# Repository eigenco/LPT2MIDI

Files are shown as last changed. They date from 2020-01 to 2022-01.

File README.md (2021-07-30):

# LPT2MIDI
- LPT2MIDI is a parallel printer port (LPT) to MIDI adapter.
- Autodesk Eagle PCB files are included.
- Uses Arduino IRQ to trigger pin reads and forwards the data to MIDI serial buffer (MIDI uses 31250 bps).
- A simple port trapping code for MS-DOS is included. This for the time being works for direct midi commands to port 330h only.
- Quickly modified version of SOFTMPU for MPU-401 compatibility.
- Tested with Roland MT-32 and Supaplex (an old MS-DOS game, requires minor modification to the code).
- Requires power through USB while operating.

Youtube link of the device in action: https://www.youtube.com/watch?v=MyJpt-w3Oao

LPT2MIDI

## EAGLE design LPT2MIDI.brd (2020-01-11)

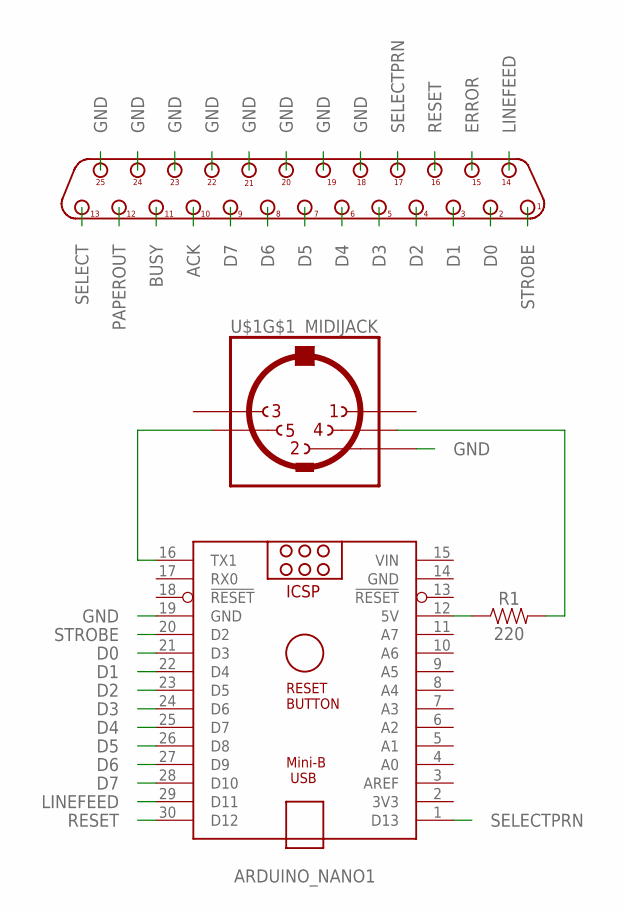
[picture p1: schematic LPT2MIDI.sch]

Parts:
ARDUINO_NANO1: ARDUINO_NANO
CON1: DB25M/90; D-25M/90
R1: 220; AXIAL-0.3
U$1: MIDIJACK; CP-2350

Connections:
ACK: CON1.10
BUSY: CON1.11
D0: ARDUINO_NANO1.21 (D3), CON1.2
D1: ARDUINO_NANO1.22 (D4), CON1.3
D2: ARDUINO_NANO1.23 (D5), CON1.4
D3: ARDUINO_NANO1.24 (D6), CON1.5
D4: ARDUINO_NANO1.25 (D7), CON1.6
D5: ARDUINO_NANO1.26 (D8), CON1.7
D6: ARDUINO_NANO1.27 (D9), CON1.8
D7: ARDUINO_NANO1.28 (D10), CON1.9
ERROR: CON1.15
GND: ARDUINO_NANO1.14 (GND), ARDUINO_NANO1.19 (GND), CON1.18, CON1.19, CON1.20, CON1.21, CON1.22, CON1.23, CON1.24, CON1.25, U$1.2
LINEFEED: ARDUINO_NANO1.29 (D11), CON1.14
unnamed: ARDUINO_NANO1.12 (5V), R1.P$1 (1)
unnamed: R1.P$2 (2), U$1.4
unnamed: ARDUINO_NANO1.16 (TX1), U$1.5
PAPEROUT: CON1.12
RESET: ARDUINO_NANO1.30 (D12), CON1.16
SELECT: CON1.13
SELECTPRN: ARDUINO_NANO1.1 (D13), CON1.17
STROBE: ARDUINO_NANO1.20 (D2), CON1.1
VIN: ARDUINO_NANO1.15 (VIN)

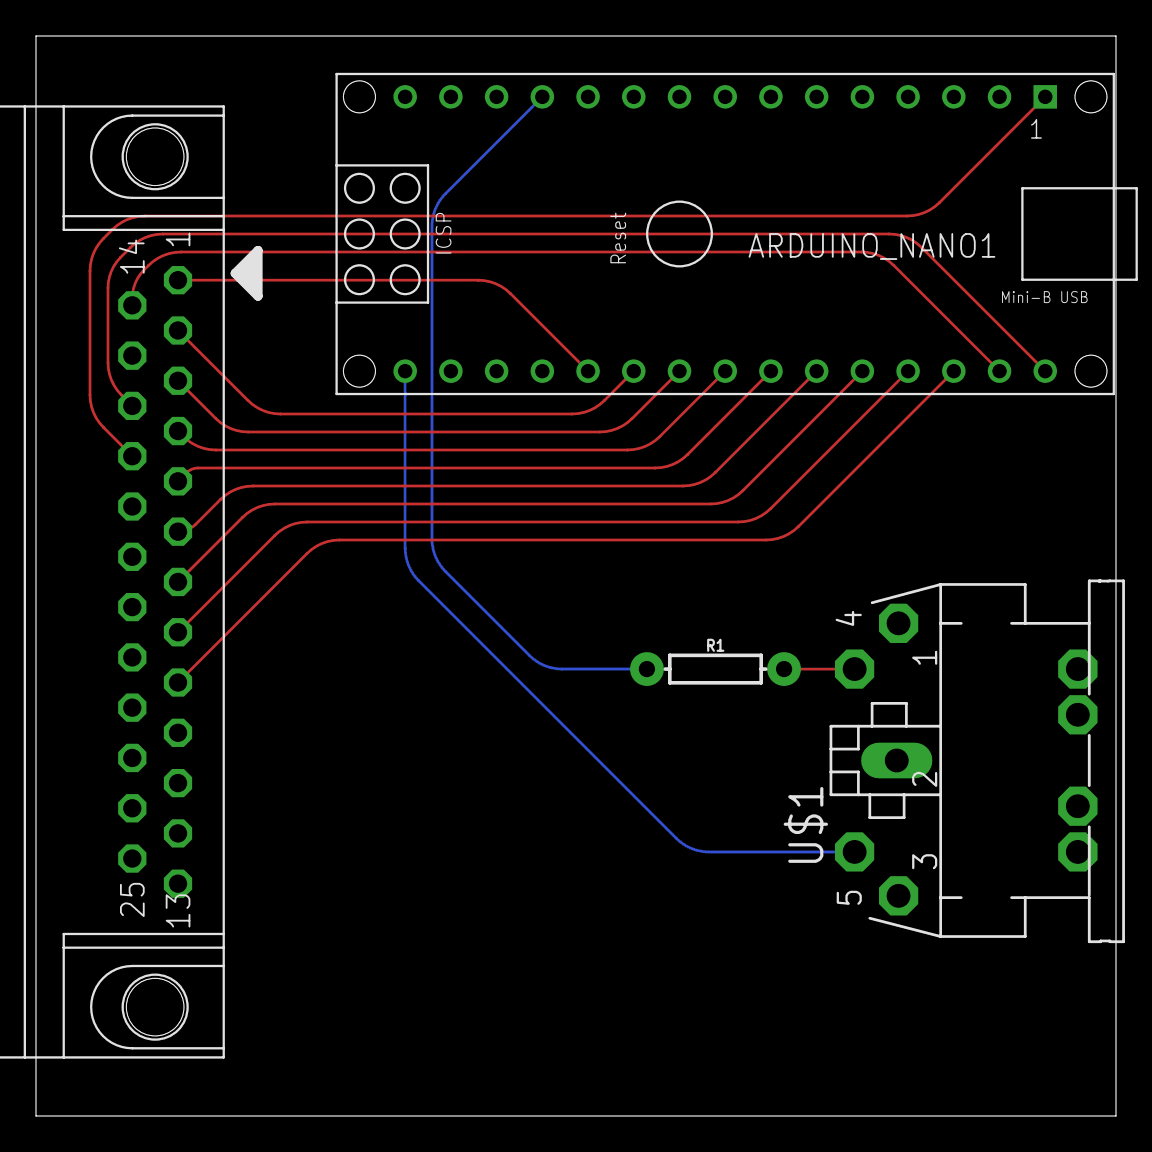
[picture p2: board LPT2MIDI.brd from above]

Board: 2 copper layers, 60.0 x 60.0 mm, 4 parts (0 on the bottom side), 16 nets.

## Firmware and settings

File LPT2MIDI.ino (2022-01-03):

#include "Fifo.h"

static Fifo<byte, 192> fifo;

void setup() {
  static byte MASKB = B00000111; // Using lower 3 bits of the B port
  static byte MASKD = B11111000; // Using upper 5 bits of the D port
  // Set only the required bits to input, leaving all the other bits unchanged
  DDRB &= ~MASKB;
  DDRD &= ~MASKD;
  Serial.begin(31250);
  auto receive = []() { fifo.push(((PIND & MASKD) >> 3) | ((PINB & MASKB) << 5)); };
  attachInterrupt(digitalPinToInterrupt(2), receive, RISING);
}

void loop() {
  // TODO: we could check here for fifo overflow using the fifo.full()
  //       function and notifying somehow the user. May be by blinking
  //       the LED?
  if (!fifo.empty()) {
    Serial.write(fifo.pop());
  }
}

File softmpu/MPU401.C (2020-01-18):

/*
 *  Copyright (C) 2002-2012  The DOSBox Team
 *  Copyright (C) 2013-2014  bjt, elianda
 *
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
 *  You should have received a copy of the GNU General Public License
 *  along with this program; if not, write to the Free Software
 *  Foundation, Inc., 59 Temple Place - Suite 330, Boston, MA 02111-1307, USA.
 */

/*
 * ------------------------------------------
 * SoftMPU by bjt - Software MPU-401 Emulator
 * ------------------------------------------
 *
 * Based on original mpu401.c from DOSBox
 *
 */

/* SOFTMPU: Moved exported functions & types to header */
#include "export.h"

/* SOFTMPU: Don't need these includes */
/*#include <string.h>
#include "dosbox.h"
#include "inout.h"
#include "pic.h"
#include "setup.h"
#include "cpu.h"
#include "support.h"*/

/* SOFTMPU: Additional defines, typedefs etc. for C */
typedef unsigned short Bit16u;
typedef int Bits;

/*typedef void (*PIC_EventHandler)(Bitu val);*/ /* SOFTMPU */

/* SOFTMPU: Stubbed functions */
void PIC_Init(void); /* SOFTMPU */
void PIC_ActivateIRQ(Bitu sbport); /* SOFTMPU */
void PIC_DeActivateIRQ(Bitu sbport); /* SOFTMPU */
void PIC_SetIRQMask(Bitu irq,bool masked);
void PIC_AddEvent(EventID event,Bitu delay);
void PIC_RemoveEvents(EventID event);

void MIDI_Init(Bitu mpuport,Bitu sbport,Bitu serialport,OutputMode outputmode,bool delaysysex,bool fakeallnotesoff);
void MIDI_RawOutByte(Bit8u data);
bool MIDI_Available(void);

void MPU401_Event(void);
void MPU401_ResetDone(void); /* SOFTMPU */
void MPU401_EOIHandler(void);
static void MPU401_Reset(void);
static void MPU401_EOIHandlerDispatch(void);

#define MPU401_VERSION  0x15
#define MPU401_REVISION 0x01
#define MPU401_QUEUE 32
#define MPU401_TIMECONSTANT 58000 /* SOFTMPU: Was 60000 */
#define MPU401_RESETBUSY 27*(RTCFREQ/1000) /* SOFTMPU */

enum MpuMode { M_UART,M_INTELLIGENT };
typedef enum MpuMode MpuMode; /* SOFTMPU */
enum MpuDataType {T_OVERFLOW,T_MARK,T_MIDI_SYS,T_MIDI_NORM,T_COMMAND};
typedef enum MpuDataType MpuDataType; /* SOFTMPU */

/* Messages sent to MPU-401 from host */
#define MSG_EOX                         0xf7
#define MSG_OVERFLOW                    0xf8
#define MSG_MARK                        0xfc

/* Messages sent to host from MPU-401 */
#define MSG_MPU_OVERFLOW                0xf8
#define MSG_MPU_COMMAND_REQ             0xf9
#define MSG_MPU_END                     0xfc
#define MSG_MPU_CLOCK                   0xfd
#define MSG_MPU_ACK                     0xfe

static struct {
	bool intelligent;
	bool generate_irqs; /* SOFTMPU */
	bool mpu_ver_fix; /* SOFTMPU */
	MpuMode mode;
	Bitu sbport;
	Bitu mpuport;
	Bitu serialport;
	/*Bitu irq;*/ /* SOFTMPU */
	Bit8u queue[MPU401_QUEUE];
	Bitu queue_pos,queue_used;
	struct track {
		Bits counter;
		Bit8u value[8],sys_val;
		Bit8u vlength,length;
		MpuDataType type;
	} playbuf[8],condbuf;
	struct {
		bool conductor,cond_req,cond_set, block_ack;
		bool playing,reset;
		bool wsd,wsm,wsd_start;
		bool run_irq,irq_pending;
		bool send_now;
		bool eoi_scheduled;
		Bits data_onoff;
		Bitu command_byte,cmd_pending;
		Bit8u tmask,cmask,amask;
		Bit16u midi_mask;
		Bit16u req_mask;
		Bit8u channel,old_chan;
	} state;
	struct {
		Bit8u timebase,old_timebase;
		Bit8u tempo,old_tempo;
		Bit8u tempo_rel,old_tempo_rel;
		Bit8u tempo_grad;
		Bit8u cth_rate,cth_counter;
		bool clock_to_host,cth_active;
	} clock;
} mpu;

/* SOFTMPU: Global QEMM interface parameters accessed from MIDI_PlayMsg */
QEMMInfo qemm = { false, NULL }; /* Disabled by default */

/* SOFTMPU: Selected output mode */
extern MIDI_output_mode;

static void QueueByte(Bit8u data) {
	if (mpu.state.block_ack) {mpu.state.block_ack=false;return;}
	if (mpu.queue_used==0 && mpu.intelligent && mpu.generate_irqs) {
		mpu.state.irq_pending=true;
		PIC_ActivateIRQ(mpu.sbport); /* SOFTMPU */
	}
	if (mpu.queue_used<MPU401_QUEUE) {
		Bitu pos=mpu.queue_used+mpu.queue_pos;
		if (mpu.queue_pos>=MPU401_QUEUE) mpu.queue_pos-=MPU401_QUEUE;
		if (pos>=MPU401_QUEUE) pos-=MPU401_QUEUE;
		mpu.queue_used++;
		mpu.queue[pos]=data;
	} /*else LOG(LOG_MISC,LOG_NORMAL)("MPU401:Data queue full");*/ /* SOFTMPU */
}

static void ClrQueue(void) {
	mpu.queue_used=0;
	mpu.queue_pos=0;
}

Bitu MPU401_ReadStatus(void) { /* SOFTMPU */
	Bit8u retval=0x3f; /* Bits 6 and 7 clear */

	switch (MIDI_output_mode)
	{
	case M_MPU401:
		/* SOFTMPU: Reflect hardware DRR */
		_asm
		{
				mov     dx,mpu.mpuport
				inc     dx
				cmp     qemm.installed,1
				jne     UntrappedIn3
				mov     ax,01A00h               ; QPI_UntrappedIORead
				call    qemm.qpi_entry          ; Result in bl
				mov     al,bl
				_emit   0A8h                    ; Emit test al,(next opcode byte)
								; Effectively skips next instruction
		UntrappedIn3:   in      al,dx
				and     al,040h
				or      retval,al
		}
		break;
	case M_SBMIDI:
		/* SOFTMPU: Reflect hardware WBS */
		_asm
		{
				mov     dx,mpu.sbport
				add     dx,0Ch                  ; Select DSP write port
				cmp     qemm.installed,1
				jne     UntrappedIn
				mov     ax,01A00h               ; QPI_UntrappedIORead
				call    qemm.qpi_entry          ; Result in bl
				mov     al,bl
				_emit   0A8h                    ; Emit test al,(next opcode byte)
								; Effectively skips next instruction
		UntrappedIn:    in      al,dx
				shr     al,1
				and     al,040h
				or      retval,al
		}
		break;
	case M_SERIAL:
		/* SOFTMPU: Reflect hardware transmit register */
		_asm
		{
				mov     dx,0x37a
				cmp     qemm.installed,1
				jne     UntrappedIn2
				mov     ax,01A00h
				call    qemm.qpi_entry
				mov     al,bl
				_emit   0A8h
								
		UntrappedIn2:   in      al,dx
				xor     al,040h
				and     al,040h
				or      retval,al
		}
		break;
	default:
		break;
	}
	if (mpu.state.cmd_pending) retval|=0x40;
	if (!mpu.queue_used) retval|=0x80;

	/* SOFTMPU: Handle spinning on status with interrupts disabled */
	if (mpu.state.reset)
	{
		PIC_Update(true);
	}

	return retval;
}
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

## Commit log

2021-12-21 Improved interrupt timing behaviour.
    Removed the Serial.write() call from the interrupt routine. Added a
    FIFO buffer to accumulate the data and moved the Serial.write() into
    the main loop. Now the interrupt should come back almost instantly.
2021-12-29 Fix timing issues and an fifo wrap bug
    [LPT2MIDI.ino]

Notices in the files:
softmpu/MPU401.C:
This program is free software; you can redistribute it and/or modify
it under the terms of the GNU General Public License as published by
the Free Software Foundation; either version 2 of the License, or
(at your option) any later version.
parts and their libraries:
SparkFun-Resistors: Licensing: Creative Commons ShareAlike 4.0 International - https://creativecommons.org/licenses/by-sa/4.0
